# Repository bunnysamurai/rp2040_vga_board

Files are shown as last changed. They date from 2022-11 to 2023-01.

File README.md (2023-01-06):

# Intro
A modified version of the RP2040 vga support board from Raspberry Pi.

Source VGA board can be found [here](https://datasheets.raspberrypi.com/rp2040/VGA-KiCAD.zip).

As a design goal, this board is intended to support all the features made available from the [RP2040 DOOM](https://kilograham.github.io/rp2040-doom/) project:
- Keyboard input
- Full colour VGA
- Original(ish) sound
- Multiplayer (over I2C)

# Tools
KiCad: version 6.0.9, at least

Design rules follow [those documented by PCBWay](https://www.pcbway.com/capabilities.html)

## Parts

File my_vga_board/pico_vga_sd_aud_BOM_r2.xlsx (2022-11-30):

RPI-PVAS pico_vga_sd_aud BOM Rev2
17/079/2020
Reference designators | Quantity | Manufacturer Part Number (MPN) | Manufacturer | Description | Value
C1, C2 | 2 | GCM188R71C105KA64J | Murata | CAP CER 1UF 16V X7R 0603 | 1u
C9, C11 | 2 | GRM188R71A225KE15D | Murata | CAP CER 2.2UF 10V X7R 0603 | 2.2u
C3, C10, C16, C19 | 4 | GRM188R61A106KE69J | Murata | CAP CER 10UF 10V X5R 0603 | 10u
C4, C5, C6, C7, C8, C12, C13 | 7 | GRM155R71E104KE14J | Murata | CAP CER 0.1UF 25V X7R 0402 | 100n
C14, C15, C21 | 3 | GRM219R60J476ME44D | Murata | CAP CER 47UF 6.3V X5R 0805 | 47u
C17, C18 | 2 | GRM155R71H222KA01D | Murata | CAP CER 2200PF 50V X7R 0402 | 2.2n
D1 | 1 | MBR120VLSFT1G | ON Semiconductor | DIODE SCHOTTKY 20V 1A SOD123FL | MBR120VLSFT1G
J1, J2 | 2 | SJ-3523-SMT-TR | CUI Devices | CONN JACK STEREO 3.5MM SMD R/A | SJ-3523-SMT
J3 | 1 | 104031-0811 | Molex | CONN MICRO SD CARD PUSH-PULL R/A | 104031-0811
J4 | 1 | L77HDE15SD1CH4F | Amphenol ICC (Commercial Products) | CONN DSUB HD RCPT 15POS R/A SLDR | L77HDE15SD1CH4F
J5 | 1 | 10103594-0001LF | Amphenol ICC (FCI) | CONN RCPT USB2.0 MICRO B SMD R/A | 10103594-0001LF
J6 | 1 | TSW-102-23-T-S | Samtec Inc. | CONN HEADER VERT 2POS 2.54MM | TSW-102-23-T-S
J7 | 1 | 67997-208HLF | Amphenol ICC (FCI) | CONN HEADER VERT 8POS 2.54MM | 67997-208HLF
R1, R2 | 2 | RC0402FR-07220RL | Yageo | RES SMD 220 OHM 1% 1/16W 0402 | 220
R3, R4 | 2 | RC0402FR-07100RL | Yageo | RES SMD 100 OHM 1% 1/16W 0402 | 100
R5, R6 | 2 | RC0402FR-07470RP | Yageo | RES SMD 470 OHM 1% 1/16W 0402 | 470
R7, R8 | 2 | RC0402FR-071K8L | Yageo | RES SMD 1.8K OHM 1% 1/16W 0402 | 1.8K
R10, R11 | 2 | RC0402FR-0747RL | Yageo | RES SMD 47 OHM 1% 1/16W 0402 | 47
R20, R21, R22, R27, R32, R37 | 6 | RC0402FR-071KP | Yageo | RES SMD 1K OHM 1% 1/16W 0402 | 1k
R23, R24 | 2 | RC0402FR-0710KP | Yageo | RES SMD 10K OHM 1% 1/16W 0402 | 10k
R26, R31, R36 | 3 | RC0402FR-07499RL | Yageo | RES SMD 499 OHM 1% 1/16W 0402 | 499
R28, R33, R38 | 3 | RC0402FR-072KL | Yageo | RES SMD 2K OHM 1% 1/16W 0402 | 2k
R29, R34, R39 | 3 | RC0402FR-074K02L | Yageo | RES SMD 4.02K OHM 1% 1/16W 0402 | 4.02k
R30, R35, R40 | 3 | RC0402FR-078K06L | Yageo | RES SMD 8.06K OHM 1% 1/16W 0402 | 8.06k
SW1, SW2, SW3, SW4 | 4 | 434133025816 | Würth Elektronik | TACT SWITCH 4.2X3.2MM VERTICAL T | 434133025816
U1 | 1 | TLV70033DDCR | Texas Instruments | IC REG LINEAR 3.3V 200MA SOT23-5 | TLV70033DDCR
U3 | 1 | NC7WZ16P6X | ON Semiconductor | IC BUF NON-INVERT 5.5V SC70-6 | NC7WZ16P6X
U4 | 1 | PCM5101APWR | Texas Instruments | IC DAC 16/24/32BIT 384K 20TSSOP | PCM5101APWR

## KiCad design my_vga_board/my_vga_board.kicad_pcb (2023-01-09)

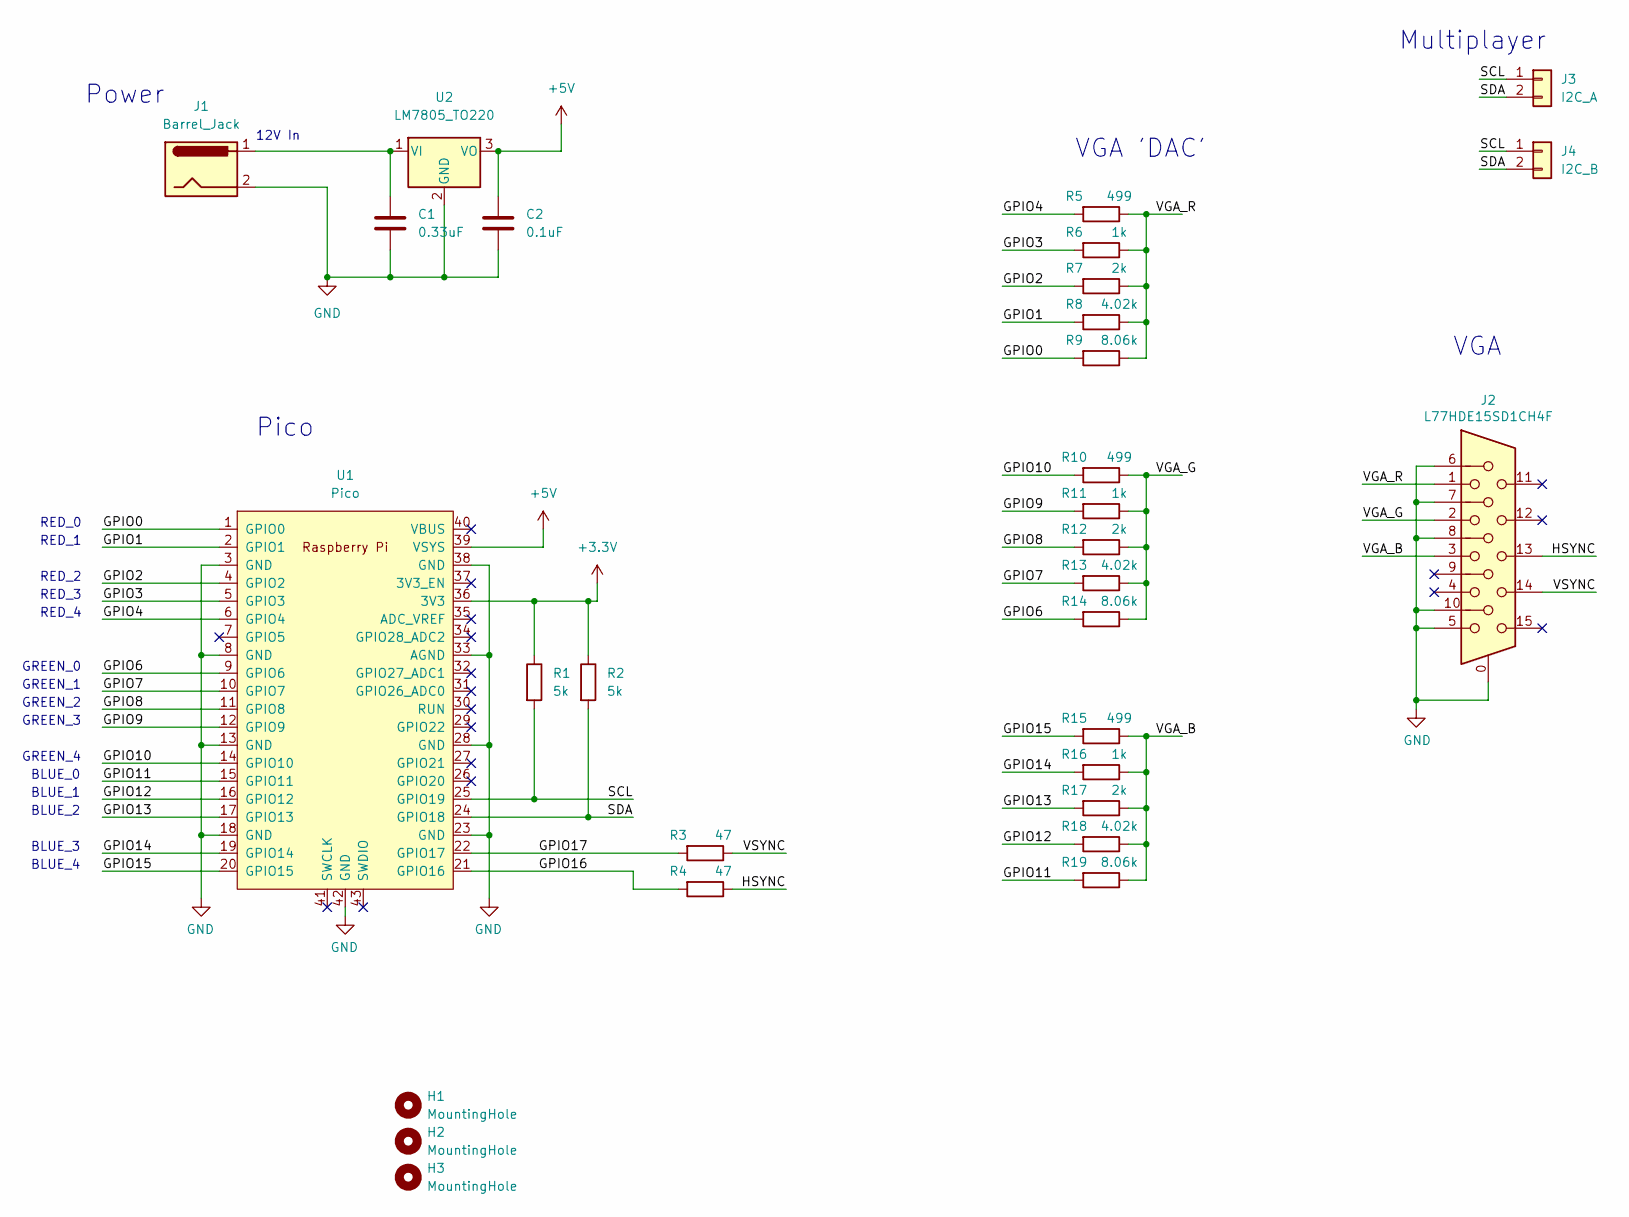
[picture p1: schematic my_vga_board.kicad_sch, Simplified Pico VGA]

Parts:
C1: 0.33uF; CP_Radial_D5.0mm_P2.00mm
C2: 0.1uF; CP_Radial_D5.0mm_P2.00mm
H1, H2, H3: MountingHole; MountingHole_4.3mm_M4
J1: Barrel_Jack; BarrelJack_Horizontal
J2: L77HDE15SD1CH4F; DSUB-15-L77HDE15SD1CH4F
J3: I2C_A; PinHeader_1x02_P2.54mm_Horizontal
J4: I2C_B; PinHeader_1x02_P2.54mm_Horizontal
R1, R2: 5k; R_Axial_DIN0207_L6.3mm_D2.5mm_P7.62mm_Horizontal
R3, R4: 47; R_Axial_DIN0207_L6.3mm_D2.5mm_P7.62mm_Horizontal
R5, R10, R15: 499; R_Axial_DIN0207_L6.3mm_D2.5mm_P7.62mm_Horizontal
R6, R11, R16: 1k; R_Axial_DIN0207_L6.3mm_D2.5mm_P7.62mm_Horizontal
R7, R12, R17: 2k; R_Axial_DIN0207_L6.3mm_D2.5mm_P7.62mm_Horizontal
R8, R13, R18: 4.02k; R_Axial_DIN0207_L6.3mm_D2.5mm_P7.62mm_Horizontal
R9, R14, R19: 8.06k; R_Axial_DIN0207_L6.3mm_D2.5mm_P7.62mm_Horizontal
U1: Pico; RPi_Pico_SMD_TH
U2: LM7805_TO220; TO-220-3_Vertical

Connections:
+3.3V: R1.1, R2.1, U1.36 (3V3)
+5V: C2.1, U1.39 (VSYS), U2.3 (VO)
/GPIO0: R9.2, U1.1 (GPIO0)
/GPIO1: R8.2, U1.2 (GPIO1)
/GPIO2: R7.2, U1.4 (GPIO2)
/GPIO3: R6.2, U1.5 (GPIO3)
/GPIO4: R5.2, U1.6 (GPIO4)
/GPIO6: R14.2, U1.9 (GPIO6)
/GPIO7: R13.2, U1.10 (GPIO7)
/GPIO8: R12.2, U1.11 (GPIO8)
/GPIO9: R11.2, U1.12 (GPIO9)
/GPIO10: R10.2, U1.14 (GPIO10)
/GPIO11: R19.2, U1.15 (GPIO11)
/GPIO12: R18.2, U1.16 (GPIO12)
/GPIO13: R17.2, U1.17 (GPIO13)
/GPIO14: R16.2, U1.19 (GPIO14)
/GPIO15: R15.2, U1.20 (GPIO15)
/GPIO16: R4.2, U1.21 (GPIO16)
/GPIO17: R3.2, U1.22 (GPIO17)
/HSYNC: J2.13, R4.1
/SCL: J3.1, J4.1, R1.2, U1.25 (GPIO19)
/SDA: J3.2, J4.2, R2.2, U1.24 (GPIO18)
/VGA_B: J2.3, R15.1, R16.1, R17.1, R18.1, R19.1
/VGA_G: J2.2, R10.1, R11.1, R12.1, R13.1, R14.1
/VGA_R: J2.1, R5.1, R6.1, R7.1, R8.1, R9.1
/VSYNC: J2.14, R3.1
GND: C1.2, C2.2, J1.2, J2.0, J2.5, J2.6, J2.7, J2.8, J2.10, U1.3 (GND), U1.8 (GND), U1.13 (GND), U1.18 (GND), U1.23 (GND), U1.28 (GND), U1.33 (AGND), U1.38 (GND), U1.42 (GND), U2.2 (GND)
unnamed: C1.1, J1.1, U2.1 (VI)

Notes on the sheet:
RED_3
RED_0
Pico
GREEN_0
BLUE_0
RED_4
Multiplayer
GREEN_3
Power
GREEN_4
BLUE_1
BLUE_4
GREEN_2
12V In
VGA 'DAC'
RED_1
GREEN_1
VGA
BLUE_2
RED_2
BLUE_3

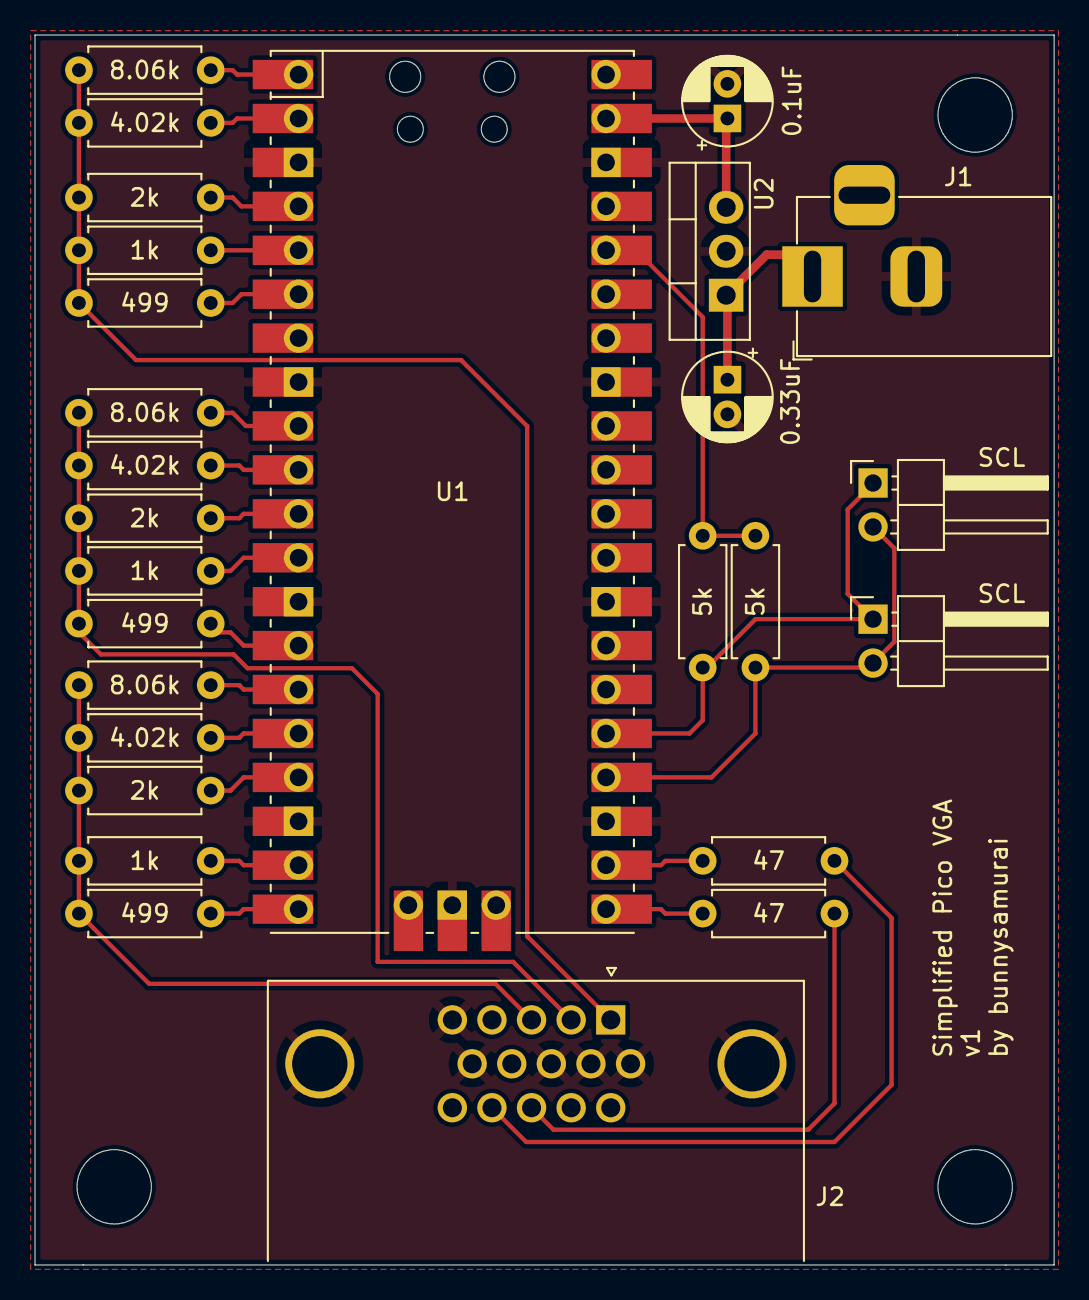
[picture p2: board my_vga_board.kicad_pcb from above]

Board: 2 copper layers, 58.9 x 71.1 mm, 30 parts (0 on the bottom side), 28 nets.

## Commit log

2022-11-30 updated commit
    [my_vga_board.kicad_pcb, my_vga_board.kicad_sch]
2022-11-30 adding power circuit, some layout schtuff
    [my_vga_board.kicad_pcb, my_vga_board.kicad_sch]
2022-12-06 updated kicad symbol lib version
2022-12-07 I don't know, some changes?
    [my_vga_board.kicad_pcb, my_vga_board.kicad_sch]
2022-12-07 adding stubs for schematic comments section
    [my_vga_board.kicad_sch]
2022-12-19 better footprints for resistance
    [my_vga_board.kicad_pcb, my_vga_board.kicad_sch]
2022-12-22 adding tracks! Neat
    [my_vga_board.kicad_pcb, my_vga_board.kicad_sch]
2022-12-22 adding version info for kicad to readme
2023-01-05 now supports multiplayer... over I2C?
    [my_vga_board.kicad_pcb, my_vga_board.kicad_sch]
2023-01-06 maybe can be fabbed?
    [my_vga_board.kicad_pcb]
2023-01-06 now with mounting holes, and accredidation, ooooh
    [my_vga_board.kicad_pcb, my_vga_board.kicad_sch]
2023-01-09 gerber files?
    [my_vga_board-B_Cu.gbr, my_vga_board-B_Mask.gbr, my_vga_board-B_Silkscreen.gbr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]
2023-01-16 comment change. I really need to get this board ordered!
    [my_vga_board.kicad_sch]

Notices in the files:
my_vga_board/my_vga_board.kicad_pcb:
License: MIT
